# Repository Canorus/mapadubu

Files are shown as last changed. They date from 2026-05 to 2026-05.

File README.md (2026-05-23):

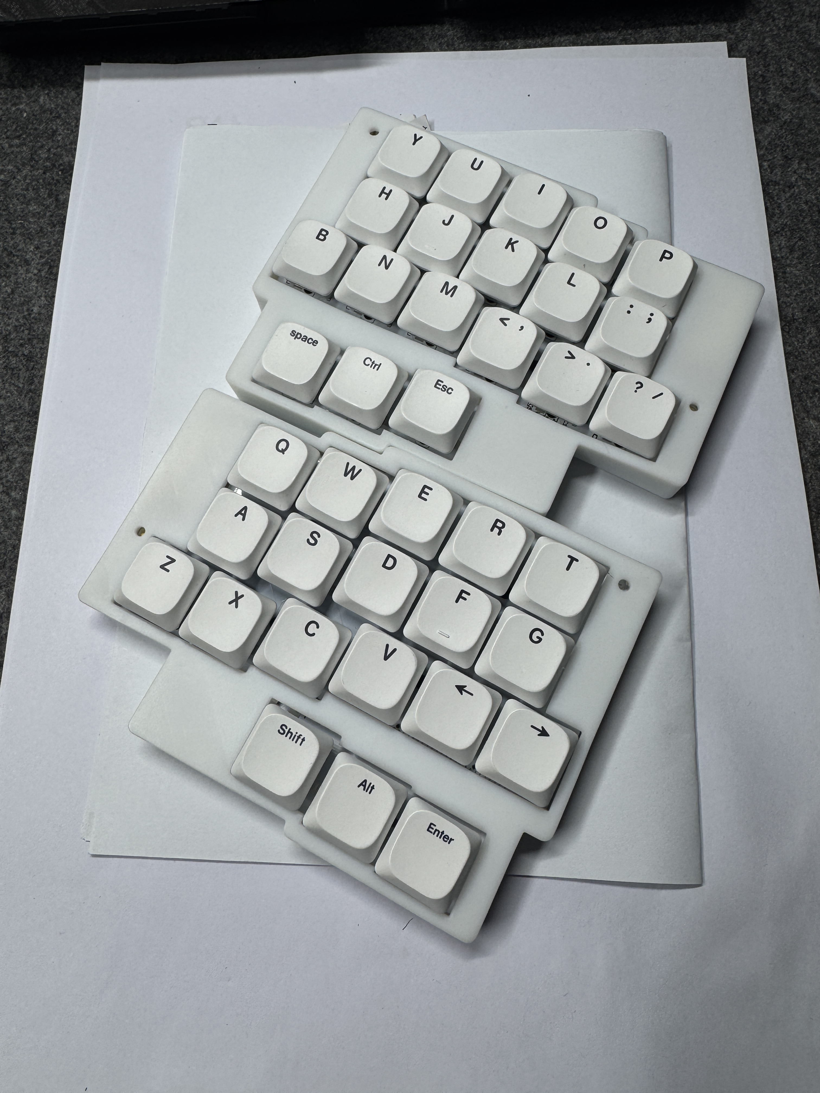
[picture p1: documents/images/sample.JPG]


# 마파두부 mapadubu
[모두부](https://github.com/yuburoll/modubu) 기반의 38키 세미 스태거 스플릿 키보드

As owner of original design mentioned, this semi-staggered layout may is in need for Korean speakers mostly, due to popular input layout called Dubeolsik among Korean users. As a result, no English tutorial will be provided from here but you are free to use online translator to proceed. AI seems to work great for that these days.

- 38키
- 우측 ㅠ키
- 완전 무선
- [zmk 펌웨어](https://github.com/canorus/zmk-mapadubu)

# BOM
링크는 참고용입니다.

|품목|수량|링크|
|:---:|:---:|:---:|
|필수|||
| 1N4148 다이오드 | 38 | https://ko.aliexpress.com/item/1005003423342580.html |
| 스위치 | 38 |  |
| 키캡 | 38 | |
| Kailh LP 핫스왑 소켓 | 38 | https://ko.aliexpress.com/item/1005009105120024.html |
| 인서트 너트(M2) | 20 | https://ko.aliexpress.com/item/1005008570811171.html |
| 스탠드오프(M2, 4mm) | 12 | https://ko.aliexpress.com/item/1005006149754236.html|
| 스크류(M2) | 8 |  |
| SPDT | 2 | https://ko.aliexpress.com/item/4000685483225.html |
| RESET 버튼 | 2 | https://ko.aliexpress.com/item/1005008865429963.html |
| SEEEDUINO XIAO BLE | 2 |  |
|옵션|||
| WS2812B mini LED | 2 | https://ko.aliexpress.com/item/4000475685852.html |
| resistor 330zR | 2 | https://ko.aliexpress.com/item/1005001436966579.html |
| capacitor 1µF | 2 | https://ko.aliexpress.com/item/32966490820.html |
| LiPo배터리(301230) | 2 | |

* 스위치는 본인의 취향에 따라 주문하되, Kailh 사의 Choc 버전을 구입하여야 합니다.
* 핫스왑 소켓에 V1, V2가 모두 호환되지만 스위치-키캡 은 V1과 V2가 호환되지 않습니다. 스위치를 V1을 구입한 경우 V1용 키캡만 쓸 수 있고, V2 스위치는 V2 키캡만 쓸 수 있습니다.
* 대표 사진의 키캡은 [이 제품](https://ko.aliexpress.com/item/1005009888904698.html) 이며 그냥 대충 검색해서 구입한 겁니다.

# 빌드 가이드

[가이드](/documents/build_guide.md)

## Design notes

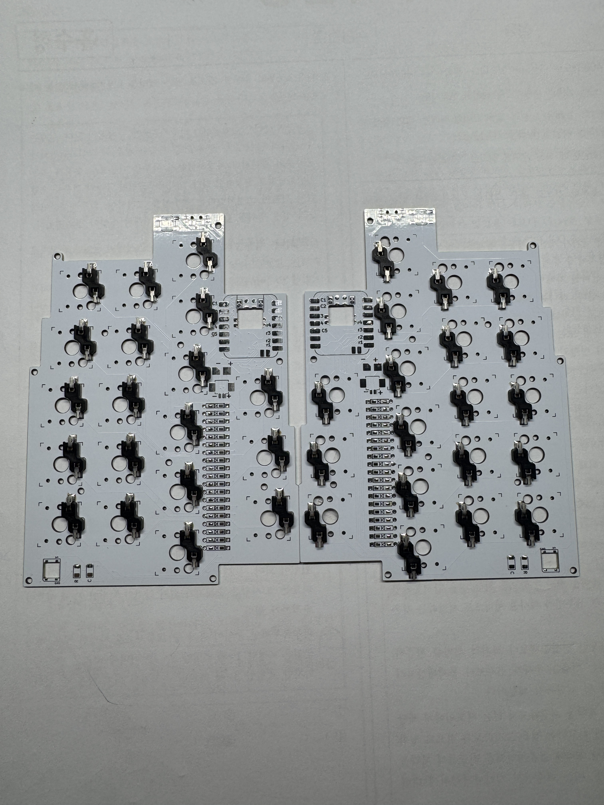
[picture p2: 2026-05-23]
documents/images/hs_socket_direction.JPG

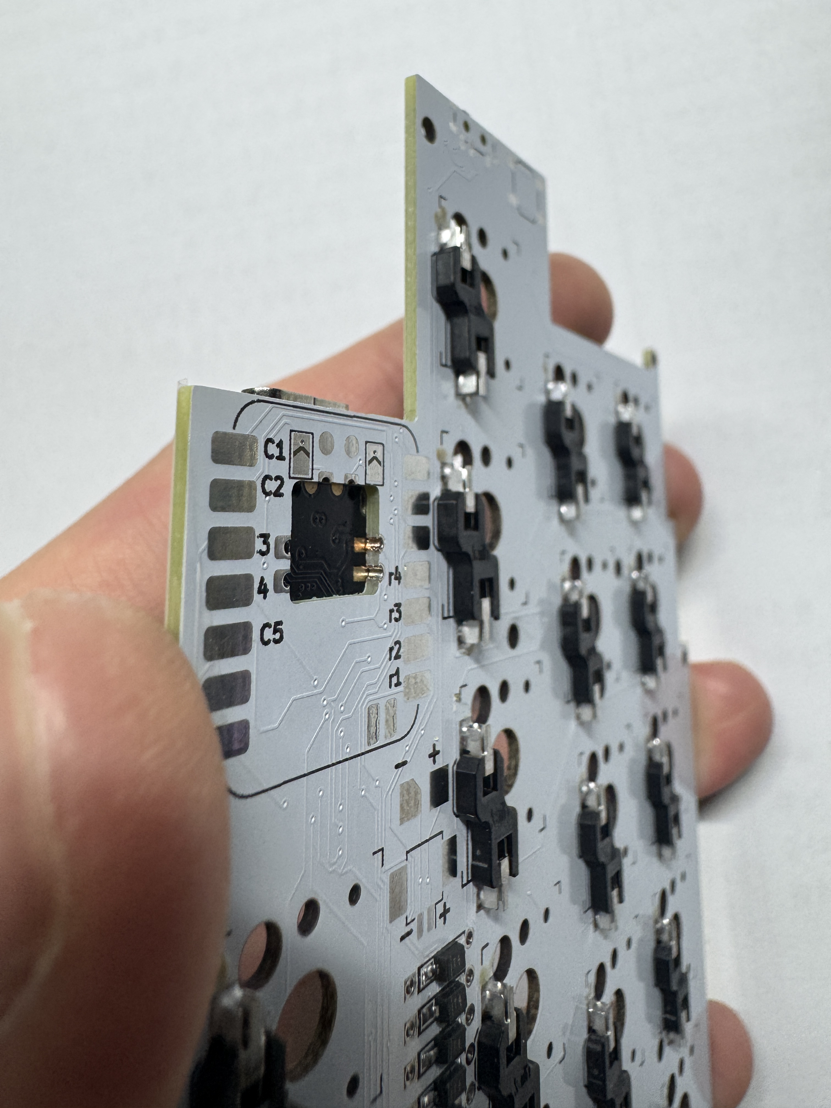
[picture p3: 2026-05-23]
documents/images/align_batt.JPG

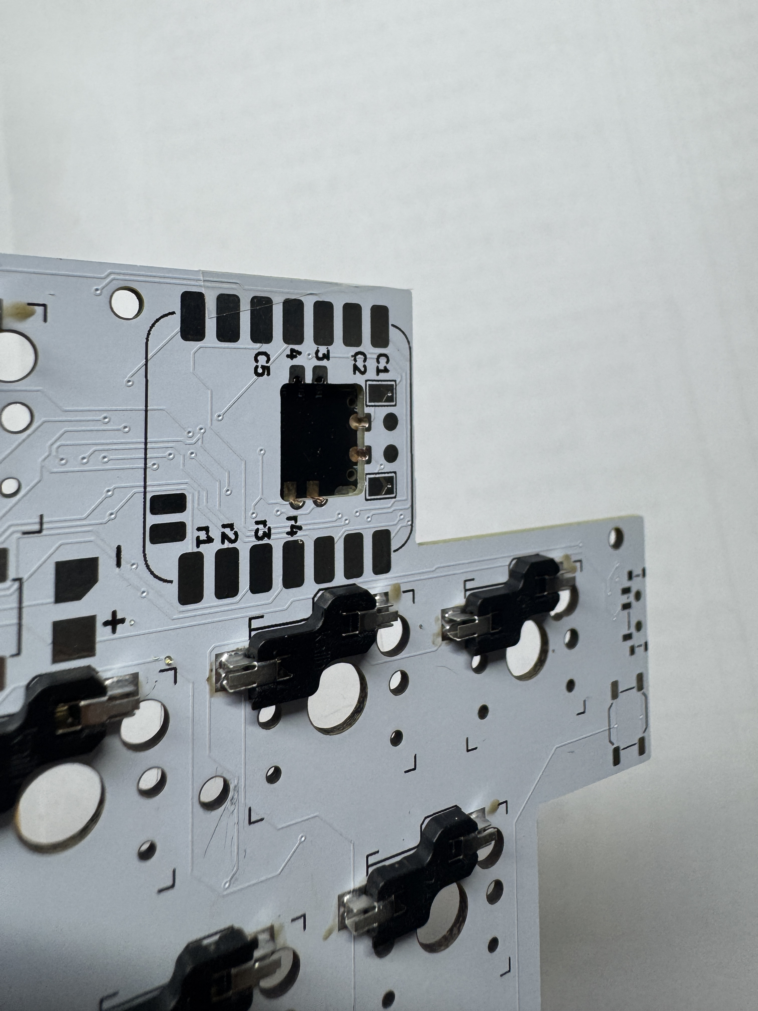
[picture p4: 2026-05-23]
documents/images/align_reset.JPG

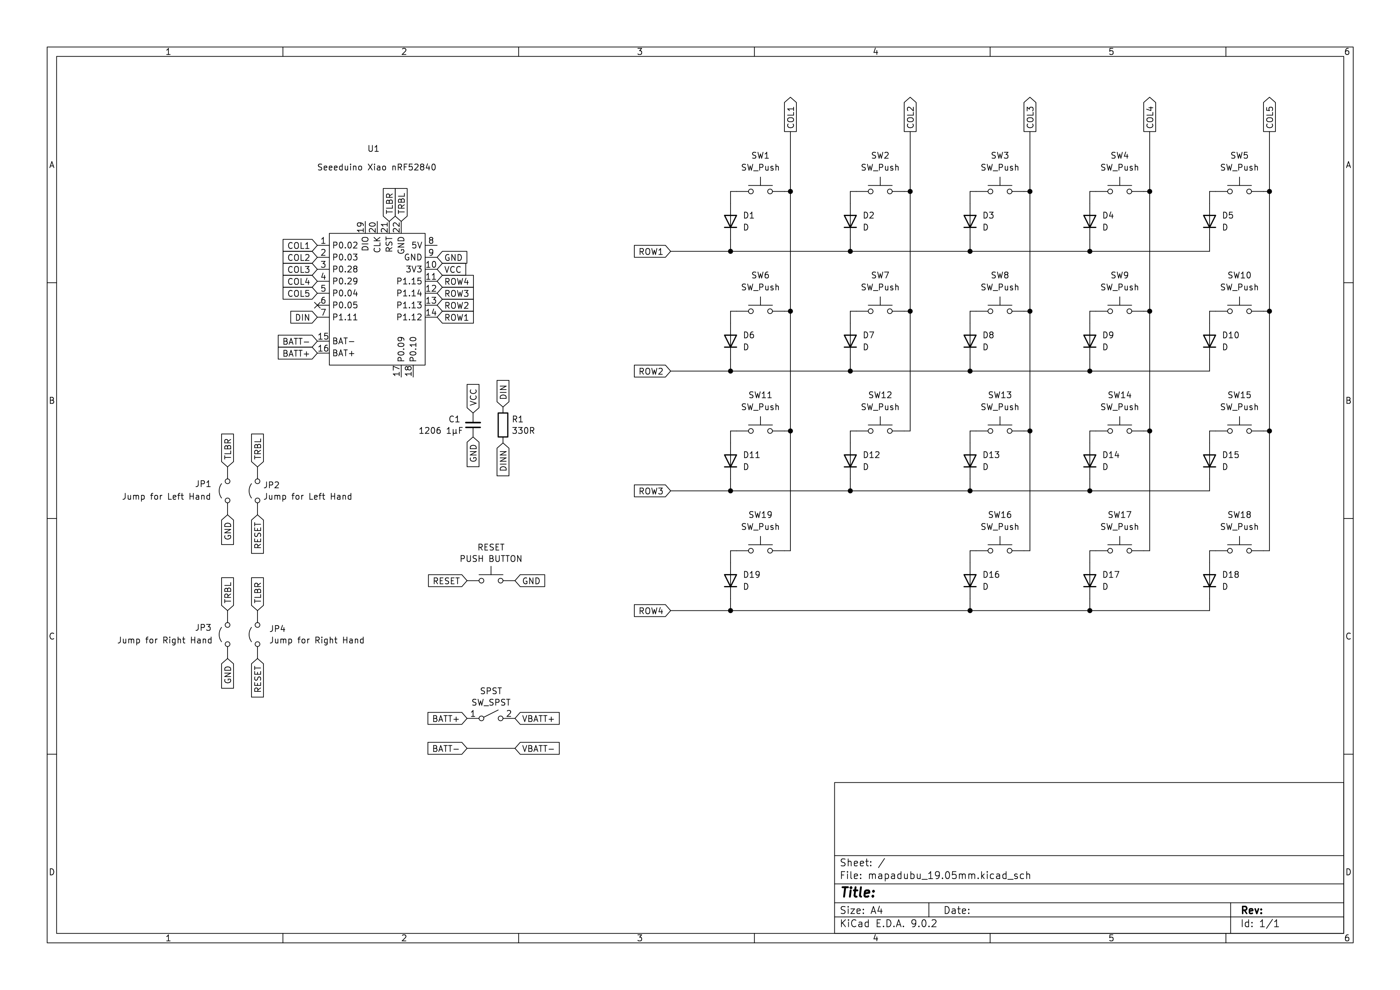
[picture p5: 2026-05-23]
kicad/mapadubu_19.05mm_scheme.png

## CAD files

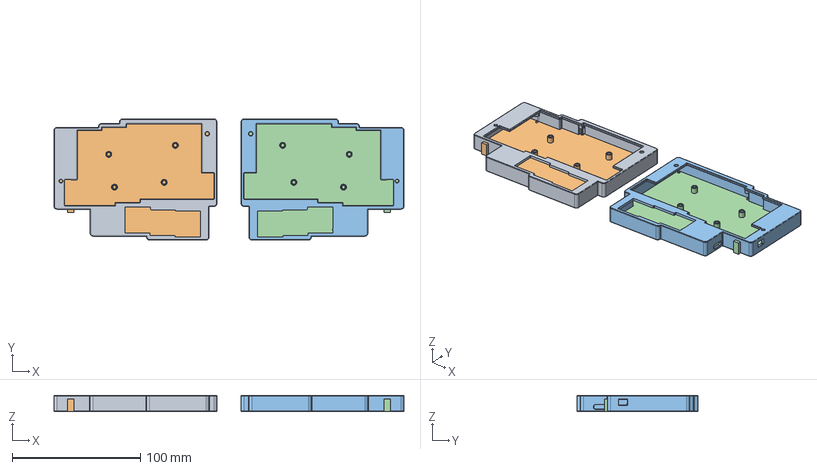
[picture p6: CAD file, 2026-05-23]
case/STEP/mapadubu_19.05mm.step
273.2 x 94.7 x 12.7 mm

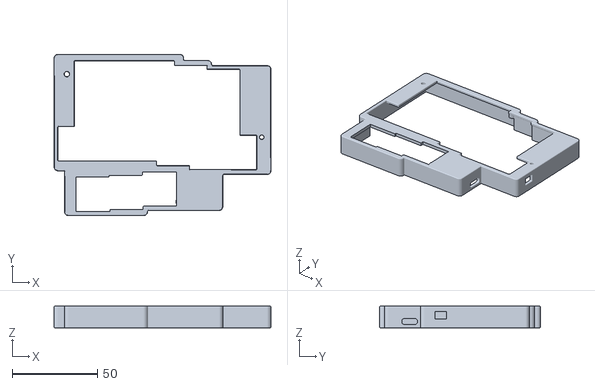
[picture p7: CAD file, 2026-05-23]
case/STL/mapadubu_19.05mm_top_right_v2.2.stl
127.2 x 94.7 x 12.7

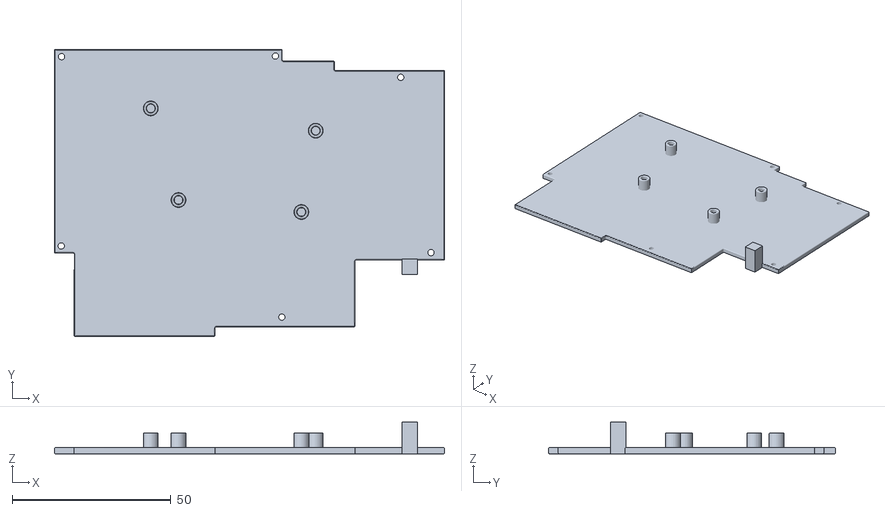
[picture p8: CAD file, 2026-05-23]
case/STL/mapadubu_19.05mm_bottom_right_v2.1.stl
122.9 x 90.4 x 10.00

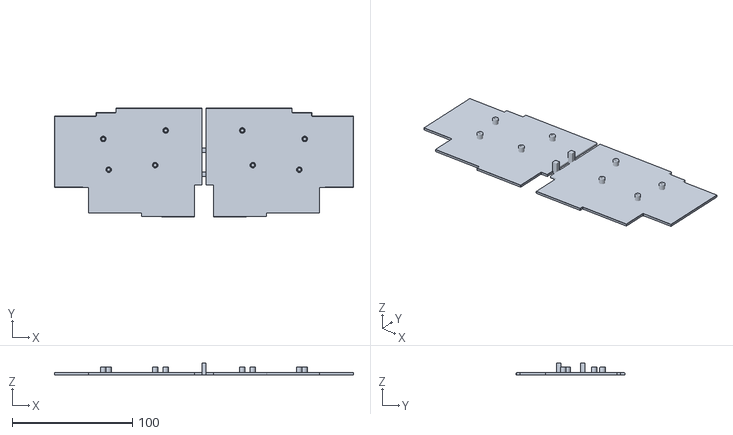
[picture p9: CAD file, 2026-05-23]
case/STL/mapadubu_19.05mm_bottom_merged_v2.1.stl
248.9 x 90.4 x 10.1

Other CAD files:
case/STL/mapadubu_19.05mm_top_left_v2.2.stl
case/STL/mapadubu_19.05mm_bottom_left_v2.1.stl

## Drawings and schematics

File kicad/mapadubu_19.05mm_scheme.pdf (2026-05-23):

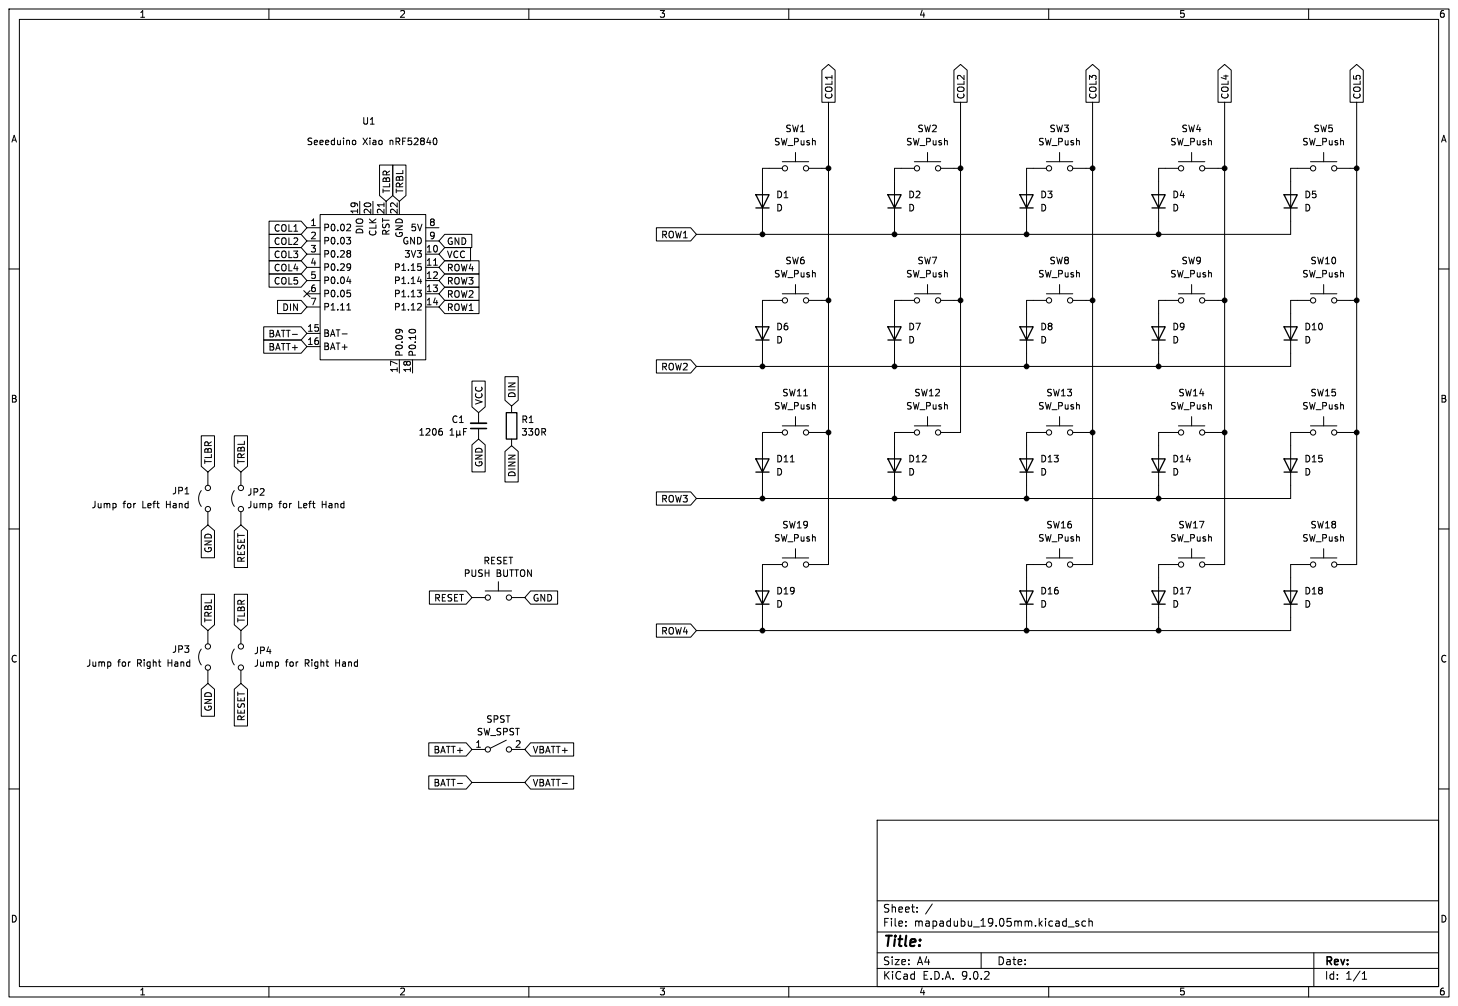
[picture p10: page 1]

Id: 1/1 Title: File: mapadubu_19.05mm.kicad_sch Sheet: / D11 D
SW19 SW_Push D19 D

Jump for Left Hand

Jump for Right Hand

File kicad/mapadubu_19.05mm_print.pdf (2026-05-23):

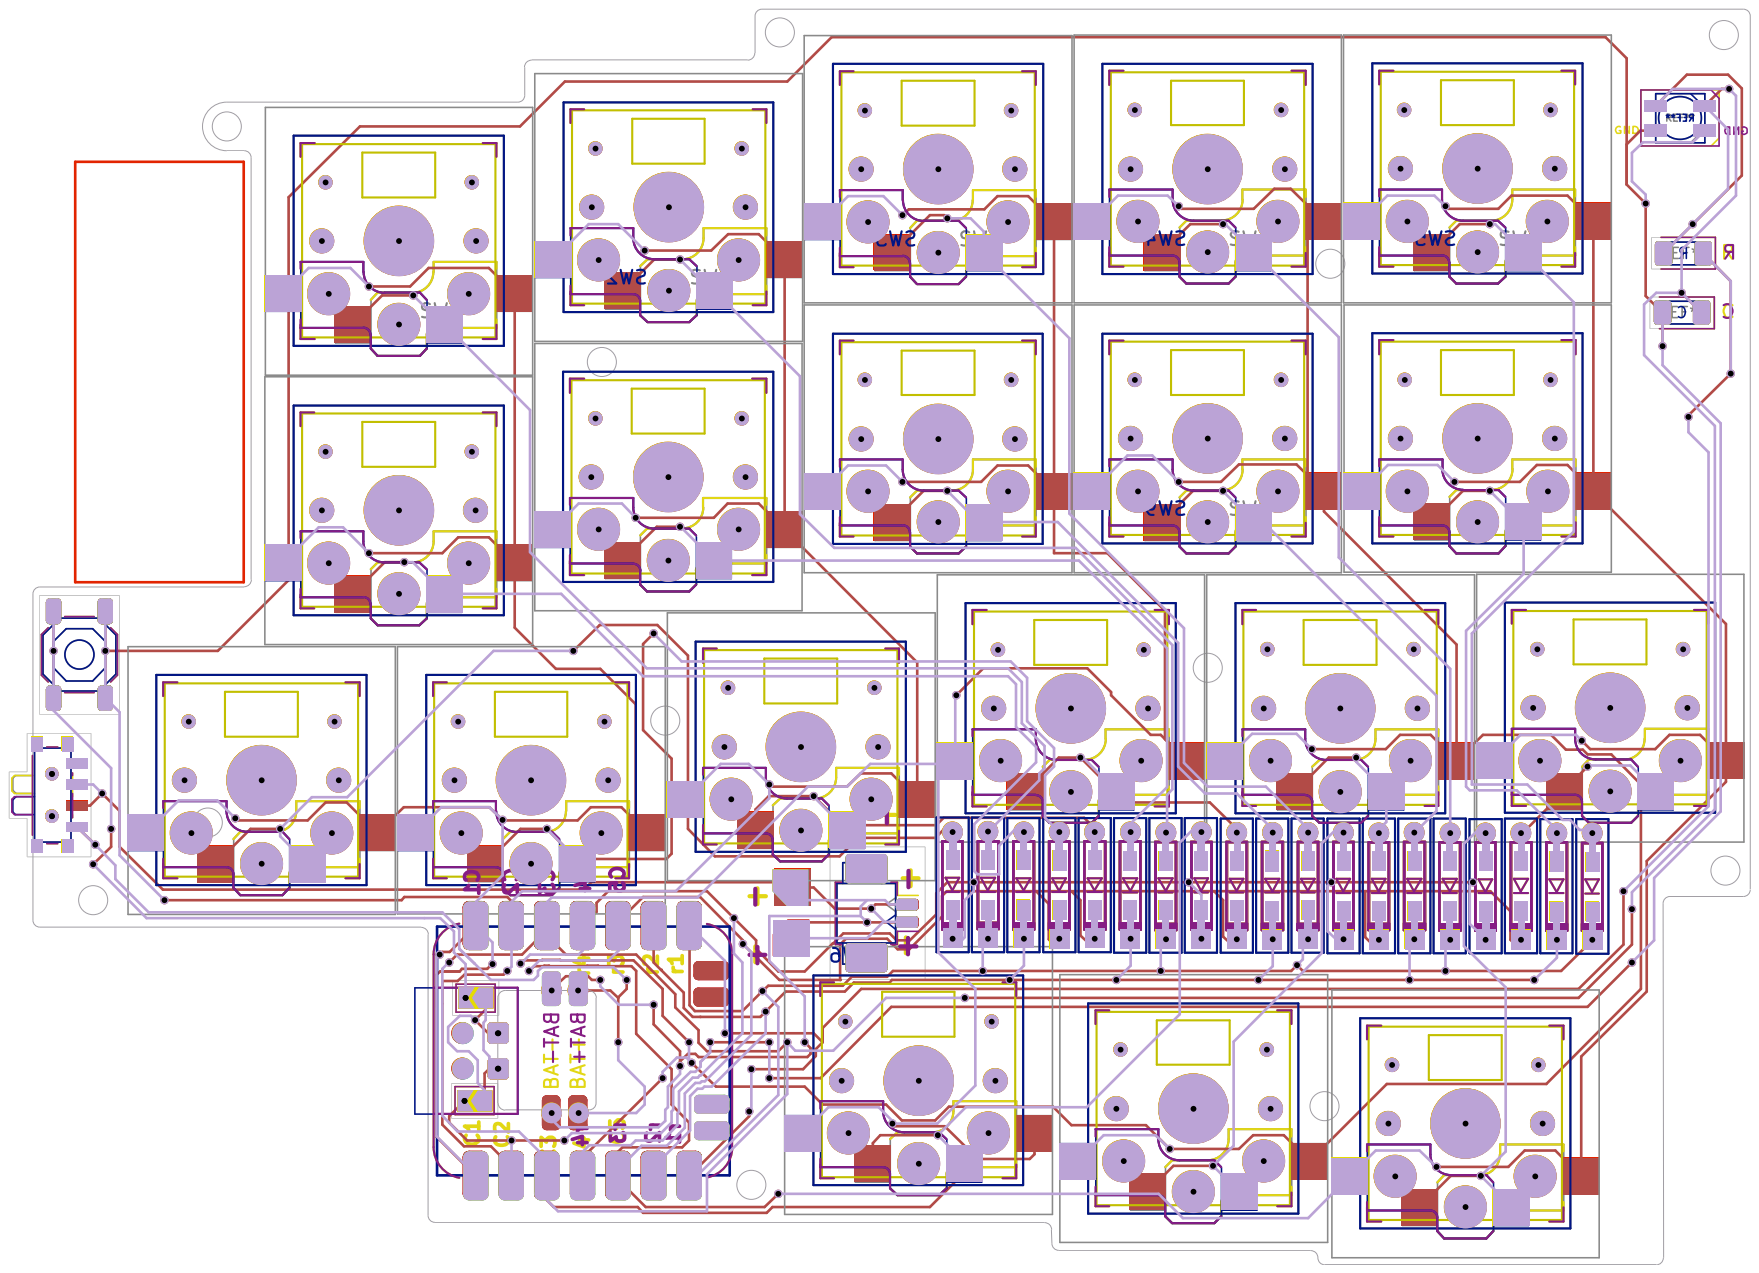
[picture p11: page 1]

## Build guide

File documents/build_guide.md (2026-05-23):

# 세 줄 요약

일단 양면 기판. 거버는 [여기](../kicad/mapadubu-gerber_v.2.2.zip)나 릴리즈에서 다운로드.

앞면에 스위치, 리셋 버튼  
뒷면에 소켓, xiao ble, LED  
다이오드, 슬라이드 스위치는 앞뒤 아무 데나 땜해도 상관없습니다.  
배터리 공간은 301230 제품을 기준으로 만들었습니다. 

# 유의사항

- 기판 두께는 1.2mm
- 다이오드 방향, LED GND 방향에 유의
- LED는 뒷면에 땜하지만 발광부가 윗면을 향하도록 해야 합니다.
- 케이스는 PLA를 권장 - ABS나 다른 재질의 경우 깨집디다.
- 핫스왑 소켓 방향에 유의 [참고 이미지](/images/hs_socket_direction.JPG)
- 하판은 최소 두께 요건 충족을 위해서 이상한 핀이 붙어있습니다. 적당히 분지르든 깎아내든 처리하시고 사용하시면 됩니다.

# xiao ble 납땜

1. xiao ble를 정위치에 놓고 테이프로 고정
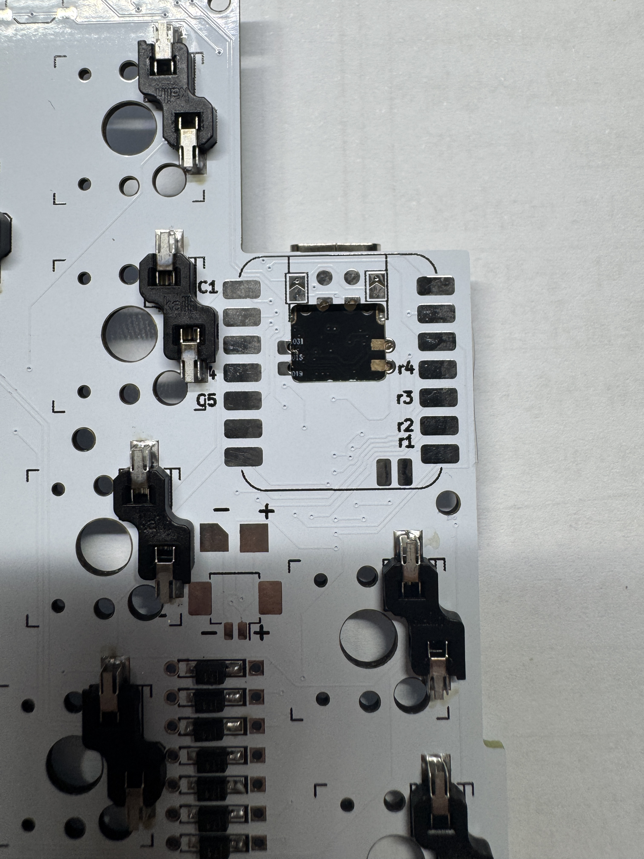
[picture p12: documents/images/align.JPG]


2. 후면 배터리핀과 RESET, GND 핀 납땜
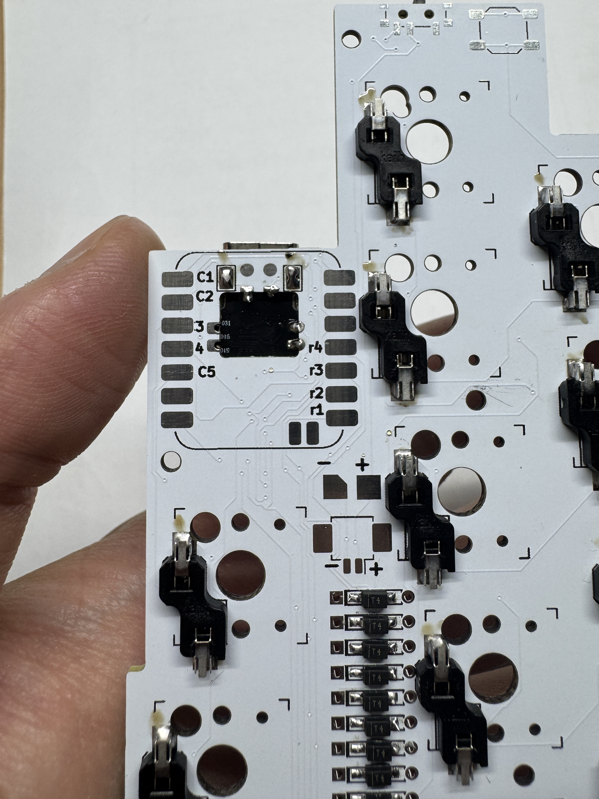
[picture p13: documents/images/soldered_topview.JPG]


3. 테이프 제거하고 나머지 핀 납땜 
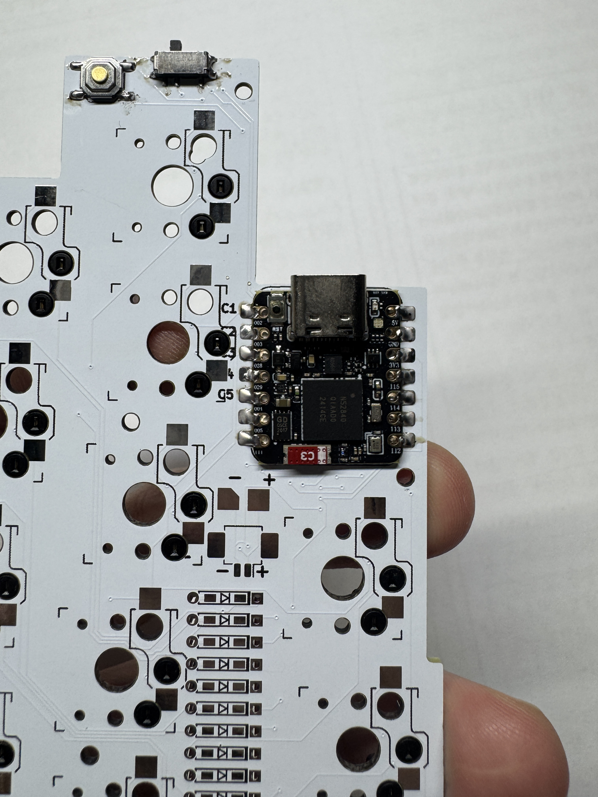
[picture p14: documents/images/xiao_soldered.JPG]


4. 점퍼 납땜

# 케이스 조립

1. 인서트를 가열해서 삽입
2. PCB를 놓고 스탠드 오프 장착
3. 하판을 PCB에 장착(상판 쪽에서 접근, 아직 스위치 끼우지 마세요)
4. 하판을 스탠드오프에 장착
5. 스위치 장착
